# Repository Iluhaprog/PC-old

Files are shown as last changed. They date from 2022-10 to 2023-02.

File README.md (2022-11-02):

# Computer from scratch 

## Control unit

Операции
1. Сложение
2. Вычитание
3. Сдвиг влево
4. Сдвиг вправо
5. Записать значение в регистр A
6. Записать значение в регистр B
7. Условный переход при A > B
8. Условный переход при A < B
9. Условный переход при A = B
10. Завершить программу

> ### Условные обозначения
> 
> **RW**: read - "0", write - "1"
> 
> **EN**: enable - "1", disable - "0"
> 
> **HS**: hide - "1", show- "0"

> ### Устройства:
> - СК - Счетчик команд
> - РКК - Регистр кода команды
> - РА - Регистр А
> - РВ - Регистр В
> - РПА - Регистр пользовательского адреса
> - РР - Регистр результата
> - АЛУ - Арифметико-логичекое устройство
> - РФ - Регистр флагов

<h2>Формат команды</h2>
<div style="padding: 20px 10px 10px 20px; border-left: 2px solid grey; margin-bottom: 20px">

<span style="border: 3px solid orange">**код операции**</span>
<span style="border: 3px solid pink">адрес</span>

</div>

### 1. Операция сложения 

Код операции - **0001**

Адрес - номер места в ОЗУ, куда необходимо записать результат

Действия для выполнения:

1. Выключаем счетчик команд
2. Включаем чтение из ОЗУ **[R]** `0`
3. Включаем выводы ОЗУ **[EN]** `1` на чтение
4. Включаем запись в регистр пользовательских адресов (РПА) **[R]** `1`
5. Включаем выводы РПА **[EN]** для записи `1`
6. Выключаем выводы РПА **[EN]**  для записи `0`
7. Включаем запись в регистр кода команды (РКК) **[W]** `1`
8. Включаем выводы РКК **[EN]** для записи `1`
9. Выключаем выводы РКК **[EN]**  для записи `0`
10. Включаем чтение из РКК **[R]** `1`
11. Включаем выводы РКК **[EN]** для чтения `0`
12. Включаем выводы **Mode** `1`
13. Выключаем выводы ОЗУ **[EN]** `0` на чтение
14. Включаем выводы АЛУ **[EN]** для чтения
15. Включаем на запись регистр результата (РР) **[W]** `1`
16. Включаем выводы РР **[EN]** `1` для записи
17. Выключаем выводы РР **[EN]** `0` для записи
18. Выключаем выводы AЛУ **[EN]** `0` для чтения
19. Включаем чтение РР **[R]** `0`
20. Включаем выводы РР **[EN]** `1` для чтения
21. Выключаем вывод адреса из счетчика команд **[HS]** `1`
22. Включаем чтение РПА **[R]** `0`
23. Включаем выводы РПА **[EN]** `1` для чтения
24. Включаем ОЗУ на запись **[W]** `1`
25. Включаем выводы ОЗУ  **[EN]** `1` для записи
26. Выключаем выводы ОЗУ  **[EN]** `0` для записи
27. Выключаем выводы РПА **[EN]** `0` для чтения
28. Включаем вывод адреса из счетчика команд **[HS]** `0`
29. Выключаем выводы РР **[EN]** `0` для чтения
30. Включаем счетчик команд

Выводы :
1. EN СК
2. HS CK
3. EN ОЗУ
4. RW ОЗУ
5. EN РКК
6. RW РКК
7. EN PA
8. RW PA
9. EN PB
10. RW PB
11. EN PP
12. RW PP
13. EN РПА
14. RW РПА
15. АЛУ 1-бит (для выбора варианта работы АЛУ)
16. АЛУ 2-бит (для выбора варианта работы АЛУ)
17. EN АЛУ (чтение с выхода)
18. EN РФ
19. RW РФ

| Такт | Состояния на выходе | Действия |
|---|---|---|
| 1 | 0010110000001100000 | 1,2,3,4,5,6,7,8 |
| 2 | 0000101010110000100 | 9,10,11,12,13,14,15,16 |
| 3 | 0111000000101000000 | 16,17,18,19,20,21,22,23,24 |
| 4 | 1000000000000000000 | 24,25,26,27,28,28,30 |

### 2. Операция вычитания 

Код операции - **0010**

Адрес - номер места в ОЗУ, куда необходимо записать результат

Действия для выполнения:

1. Выключаем счетчик команд
2. Включаем чтение из ОЗУ **[R]** `0`
3. Включаем выводы ОЗУ **[EN]** `1` на чтение
4. Включаем запись в регистр пользовательских адресов (РПА) **[R]** `1`
5. Включаем выводы РПА **[EN]** для записи `1`
6. Выключаем выводы РПА **[EN]**  для записи `0`
7. Включаем запись в регистр кода команды (РКК) **[W]** `1`
8. Включаем выводы РКК **[EN]** для записи `1`
9. Выключаем выводы РКК **[EN]**  для записи `0`
10. Включаем чтение из РКК **[R]** `1`
11. Включаем выводы РКК **[EN]** для чтения `0`
12. Включаем выводы **Mode** `10`
13. Выключаем выводы ОЗУ **[EN]** `0` на чтение
14. Включаем выводы АЛУ **[EN]** для чтения
15. Включаем на запись регистр результата (РР) **[W]** `1`
16. Включаем выводы РР **[EN]** `1` для записи
17. Выключаем выводы РР **[EN]** `0` для записи
18. Выключаем выводы AЛУ **[EN]** `0` для чтения
19. Включаем чтение РР **[R]** `0`
20. Включаем выводы РР **[EN]** `1` для чтения
21. Выключаем вывод адреса из счетчика команд **[HS]** `1`
22. Включаем чтение РПА **[R]** `0`
23. Включаем выводы РПА **[EN]** `1` для чтения
24. Включаем ОЗУ на запись **[W]** `1`
25. Включаем выводы ОЗУ  **[EN]** `1` для записи
26. Выключаем выводы ОЗУ  **[EN]** `0` для записи
27. Выключаем выводы РПА **[EN]** `0` для чтения
28. Включаем вывод адреса из счетчика команд **[HS]** `0`
29. Выключаем выводы РР **[EN]** `0` для чтения
30. Включаем счетчик команд

Выводы :
1. EN СК
2. HS CK
3. EN ОЗУ
4. RW ОЗУ
5. EN РКК
6. RW РКК
7. EN PA
8. RW PA
9. EN PB
10. RW PB
11. EN PP
12. RW PP
13. EN РПА
14. RW РПА
15. АЛУ 1-бит (для выбора варианта работы АЛУ)
16. АЛУ 2-бит (для выбора варианта работы АЛУ)
17. EN АЛУ (чтение с выхода)
18. EN РФ
19. RW РФ

| Такт | Состояния на выходе | Действия |
|---|---|---|
| 1 | 0010110000001100000 | 1,2,3,4,5,6,7,8 |
| 2 | 0000101010110010100 | 9,10,11,12,13,14,15,16 |
| 3 | 0111000000101000000 | 16,17,18,19,20,21,22,23,24 |
| 4 | 1000000000000000000 | 24,25,26,27,28,28,30 |

### 3. Операция сдвига влево 

Код операции - **0011**

Адрес - номер места в ОЗУ, куда необходимо записать результат

Действия для выполнения:

1. Выключаем счетчик команд
2. Включаем чтение из ОЗУ **[R]** `0`
3. Включаем выводы ОЗУ **[EN]** `1` на чтение
4. Включаем запись в регистр пользовательских адресов (РПА) **[R]** `1`
5. Включаем выводы РПА **[EN]** для записи `1`
6. Выключаем выводы РПА **[EN]**  для записи `0`
7. Включаем запись в регистр кода команды (РКК) **[W]** `1`
8. Включаем выводы РКК **[EN]** для записи `1`
9. Выключаем выводы РКК **[EN]**  для записи `0`
10. Включаем чтение из РКК **[R]** `1`
11. Включаем выводы РКК **[EN]** для чтения `0`
12. Включаем выводы **Mode** `11`
13. Выключаем выводы ОЗУ **[EN]** `0` на чтение
14. Включаем выводы АЛУ **[EN]** для чтения
15. Включаем на запись регистр результата (РР) **[W]** `1`
16. Включаем выводы РР **[EN]** `1` для записи
17. Выключаем выводы РР **[EN]** `0` для записи
18. Выключаем выводы AЛУ **[EN]** `0` для чтения
19. Включаем чтение РР **[R]** `0`
20. Включаем выводы РР **[EN]** `1` для чтения
21. Выключаем вывод адреса из счетчика команд **[HS]** `1`
22. Включаем чтение РПА **[R]** `0`
23. Включаем выводы РПА **[EN]** `1` для чтения
24. Включаем ОЗУ на запись **[W]** `1`
25. Включаем выводы ОЗУ  **[EN]** `1` для записи
26. Выключаем выводы ОЗУ  **[EN]** `0` для записи
27. Выключаем выводы РПА **[EN]** `0` для чтения
28. Включаем вывод адреса из счетчика команд **[HS]** `0`
29. Выключаем выводы РР **[EN]** `0` для чтения
30. Включаем счетчик команд

Выводы :
1. EN СК
2. HS CK
3. EN ОЗУ
4. RW ОЗУ
5. EN РКК
6. RW РКК
7. EN PA
8. RW PA
9. EN PB
10. RW PB
11. EN PP
12. RW PP
13. EN РПА
14. RW РПА
15. АЛУ 1-бит (для выбора варианта работы АЛУ)
16. АЛУ 2-бит (для выбора варианта работы АЛУ)
17. EN АЛУ (чтение с выхода)
18. EN РФ
19. RW РФ

| Такт | Состояния на выходе | Действия |
|---|---|---|
| 1 | 0010110000001100000 | 1,2,3,4,5,6,7,8 |
| 2 | 0000101010110011100 | 9,10,11,12,13,14,15,16 |
| 3 | 0111000000101000000 | 16,17,18,19,20,21,22,23,24 |
| 4 | 1000000000000000000 | 24,25,26,27,28,28,30 |

### 3. Операция сдвига вправо 

Код операции - **0100**

Адрес - номер места в ОЗУ, куда необходимо записать результат

Действия для выполнения:

1. Выключаем счетчик команд
2. Включаем чтение из ОЗУ **[R]** `0`
3. Включаем выводы ОЗУ **[EN]** `1` на чтение
4. Включаем запись в регистр пользовательских адресов (РПА) **[R]** `1`
5. Включаем выводы РПА **[EN]** для записи `1`
6. Выключаем выводы РПА **[EN]**  для записи `0`
7. Включаем запись в регистр кода команды (РКК) **[W]** `1`
8. Включаем выводы РКК **[EN]** для записи `1`
9. Выключаем выводы РКК **[EN]**  для записи `0`
10. Включаем чтение из РКК **[R]** `1`
11. Включаем выводы РКК **[EN]** для чтения `0`
12. Включаем выводы **Mode** `11`
13. Выключаем выводы ОЗУ **[EN]** `0` на чтение
14. Включаем выводы АЛУ **[EN]** для чтения
15. Включаем на запись регистр результата (РР) **[W]** `1`
16. Включаем выводы РР **[EN]** `1` для записи
17. Выключаем выводы РР **[EN]** `0` для записи
18. Выключаем выводы AЛУ **[EN]** `0` для чтения
19. Включаем чтение РР **[R]** `0`
20. Включаем выводы РР **[EN]** `1` для чтения
21. Выключаем вывод адреса из счетчика команд **[HS]** `1`
22. Включаем чтение РПА **[R]** `0`
23. Включаем выводы РПА **[EN]** `1` для чтения
24. Включаем ОЗУ на запись **[W]** `1`
25. Включаем выводы ОЗУ  **[EN]** `1` для записи
26. Выключаем выводы ОЗУ  **[EN]** `0` для записи
27. Выключаем выводы РПА **[EN]** `0` для чтения
28. Включаем вывод адреса из счетчика команд **[HS]** `0`
29. Выключаем выводы РР **[EN]** `0` для чтения
30. Включаем счетчик команд

Выводы :
1. EN СК
2. HS CK
3. EN ОЗУ
4. RW ОЗУ
5. EN РКК
6. RW РКК
7. EN PA
8. RW PA
9. EN PB
10. RW PB
11. EN PP
12. RW PP
13. EN РПА
14. RW РПА
15. АЛУ 1-бит (для выбора варианта работы АЛУ)
16. АЛУ 2-бит (для выбора варианта работы АЛУ)
17. EN АЛУ (чтение с выхода)
18. EN РФ
19. RW РФ

| Такт | Состояния на выходе | Действия |
|---|---|---|
| 1 | 0010110000001100000 | 1,2,3,4,5,6,7,8 |
| 2 | 0000101010110001100 | 9,10,11,12,13,14,15,16 |
| 3 | 0111000000101000000 | 16,17,18,19,20,21,22,23,24 |
| 4 | 1000000000000000000 | 24,25,26,27,28,28,30 |

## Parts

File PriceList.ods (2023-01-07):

Устройства выбора режима работы АЛУ, сумматор вычитатель, выводное устройство |  |  |  |  | Дополнительные элементы
Логический элемент | Модель микросхемы | Стоимость | Количество | Сумма | Элемент | Количество | Стоимость | Сумма
2И | SN74HC08N | 1.9 | 9 | 17.1 | DIP-14 панели | 30 | 0.2 | 6
НЕ | SN74HC05N | 1.9 | 6 | 11.4 | Вилка (1 на 40) | 1 | 2.05 | 2.05
XOR | SN74HC86N | 1.45 | 7 | 10.15 | Резисторы 1кОМ | 40 | 0.08 | 3.2
2ИЛИ | SN74HC32N | 1.75 | 4 | 7 | Конденсатры 1мкФ | 40 | 0.2 | 8
3ИЛИ-НЕ | SN74HC27N | 1.15 | 4 | 4.6
 |  |  |  |  |  | я
Общая стоимость |  |  | 30 | 50.25 |  |  |  | 19.25
Сумма
69.5

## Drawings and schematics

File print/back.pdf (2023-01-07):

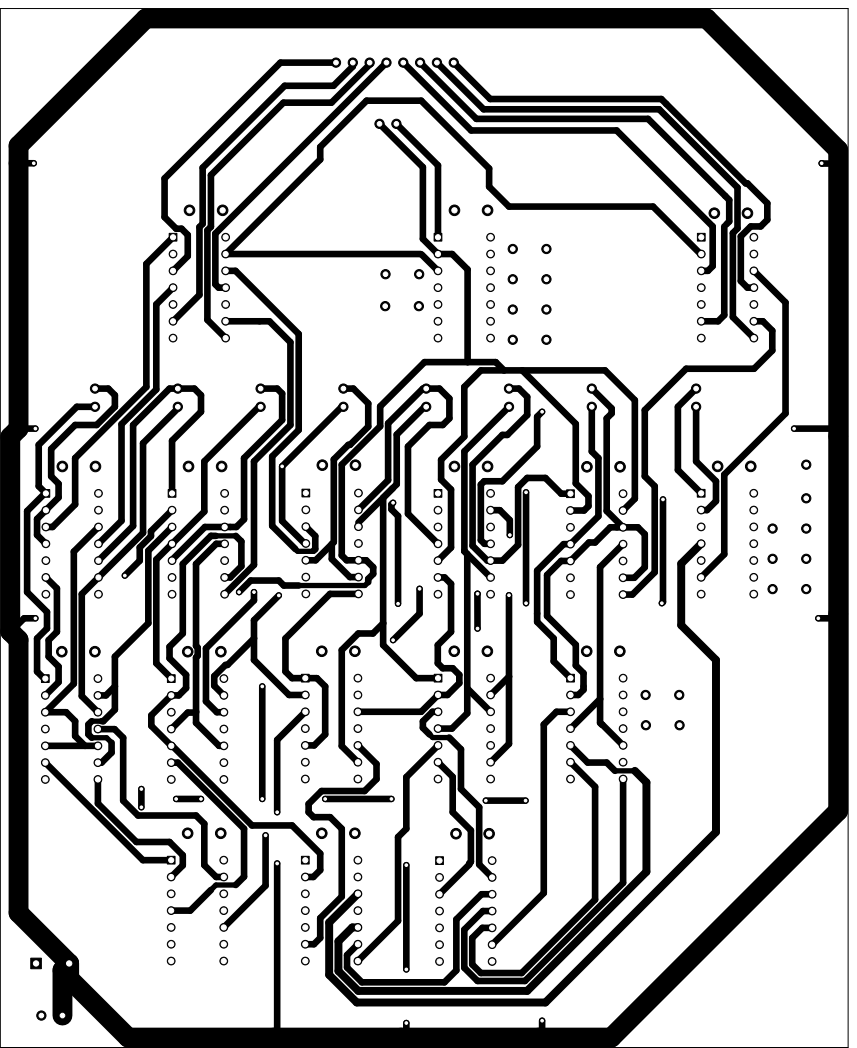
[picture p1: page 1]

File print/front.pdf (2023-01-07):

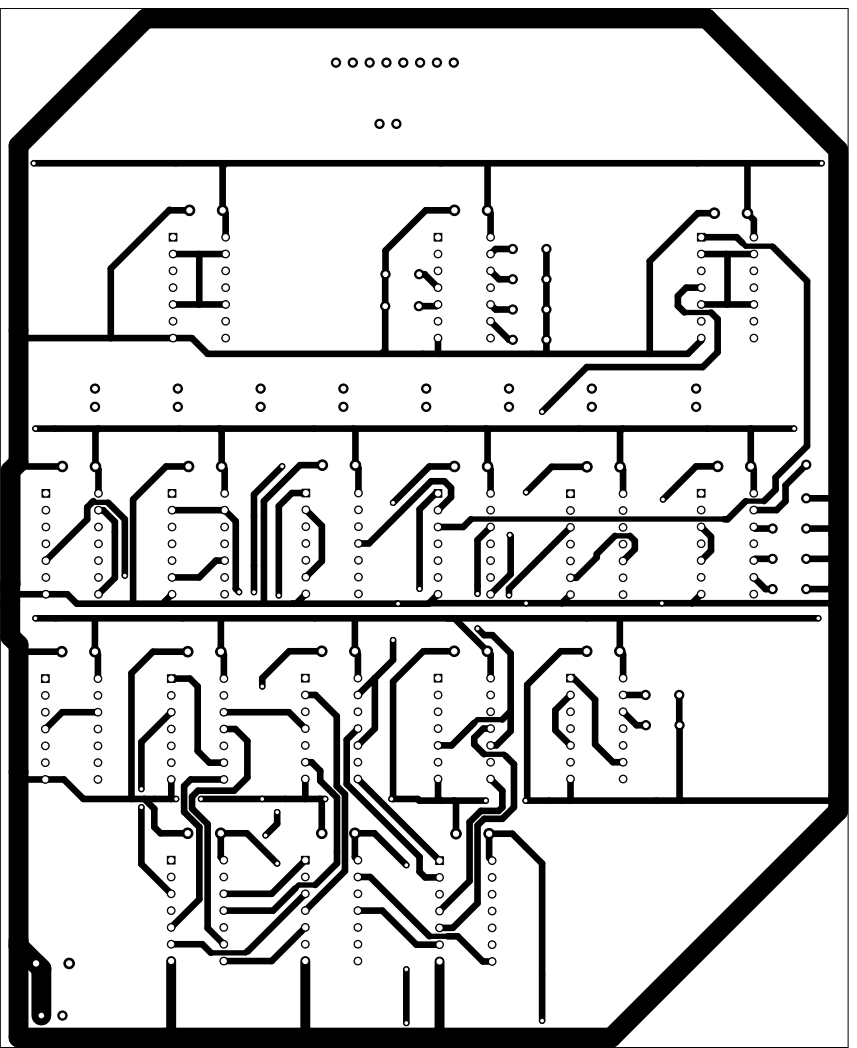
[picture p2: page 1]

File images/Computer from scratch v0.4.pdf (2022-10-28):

? ??

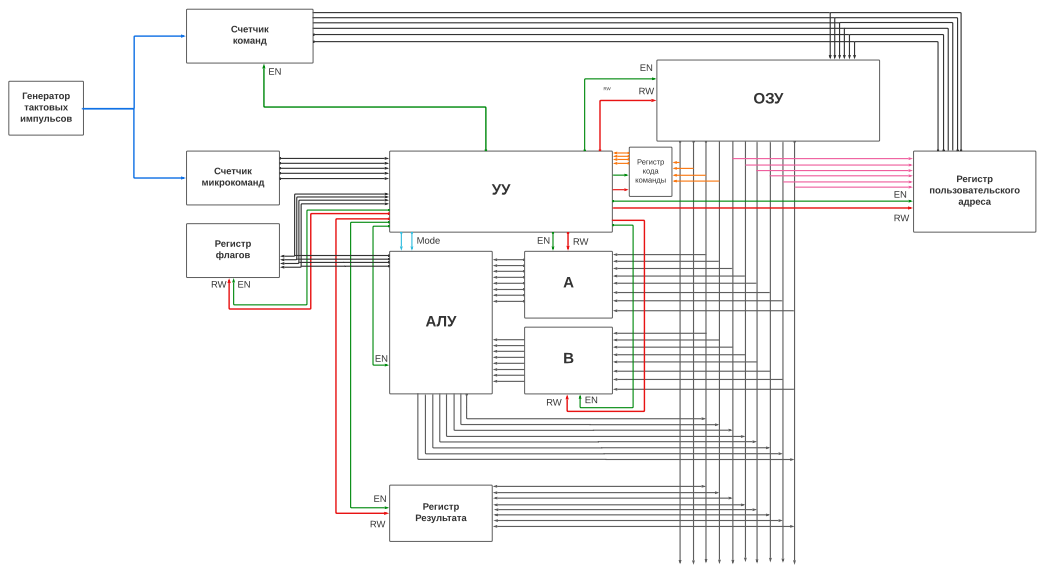
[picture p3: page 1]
Mode

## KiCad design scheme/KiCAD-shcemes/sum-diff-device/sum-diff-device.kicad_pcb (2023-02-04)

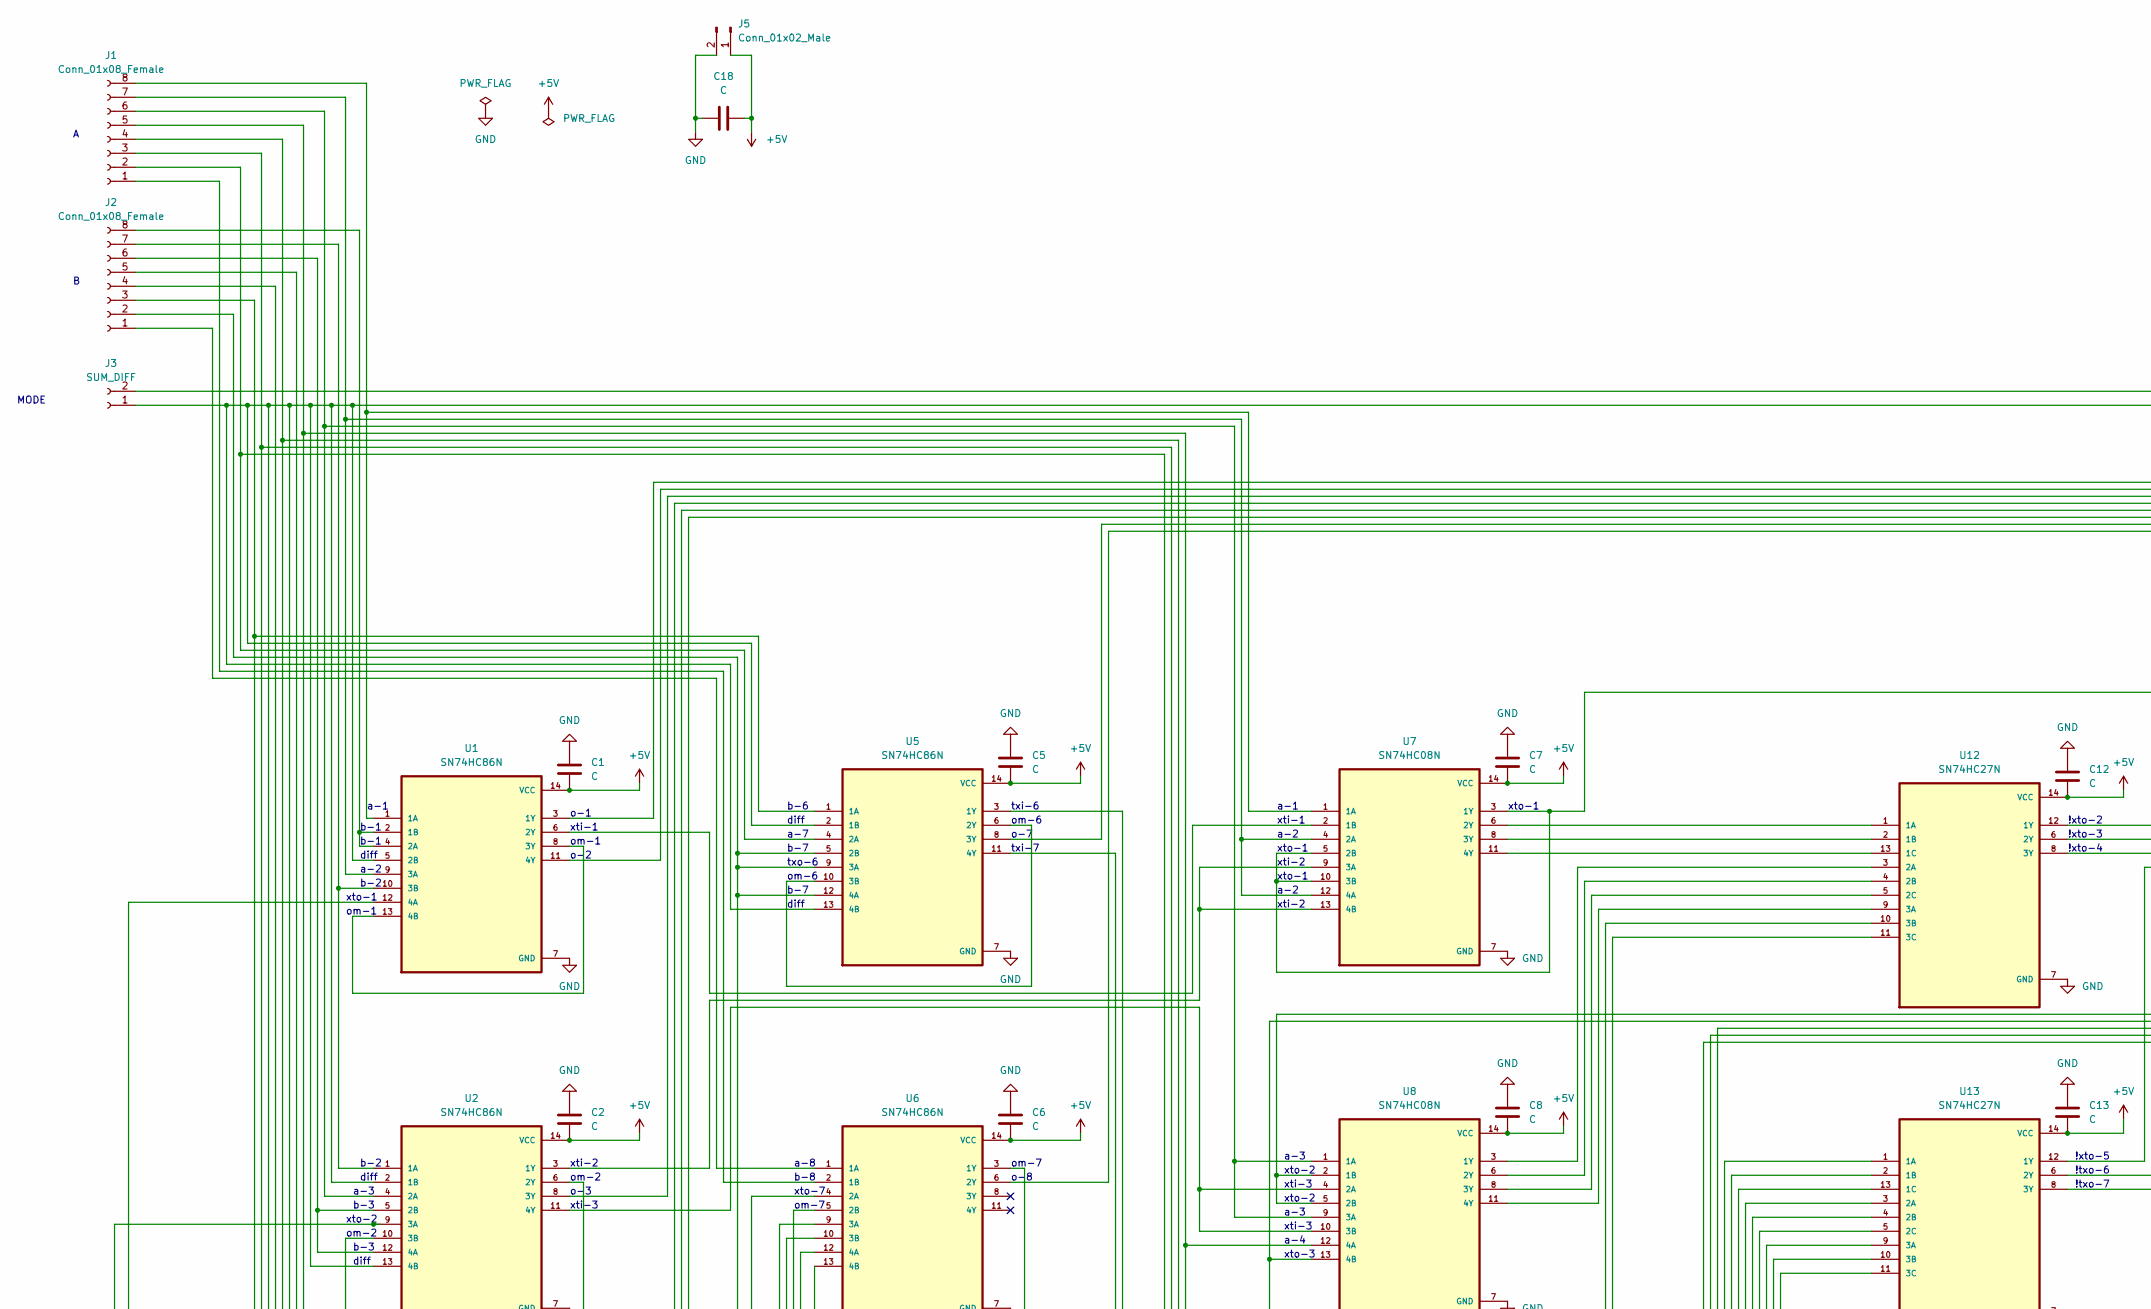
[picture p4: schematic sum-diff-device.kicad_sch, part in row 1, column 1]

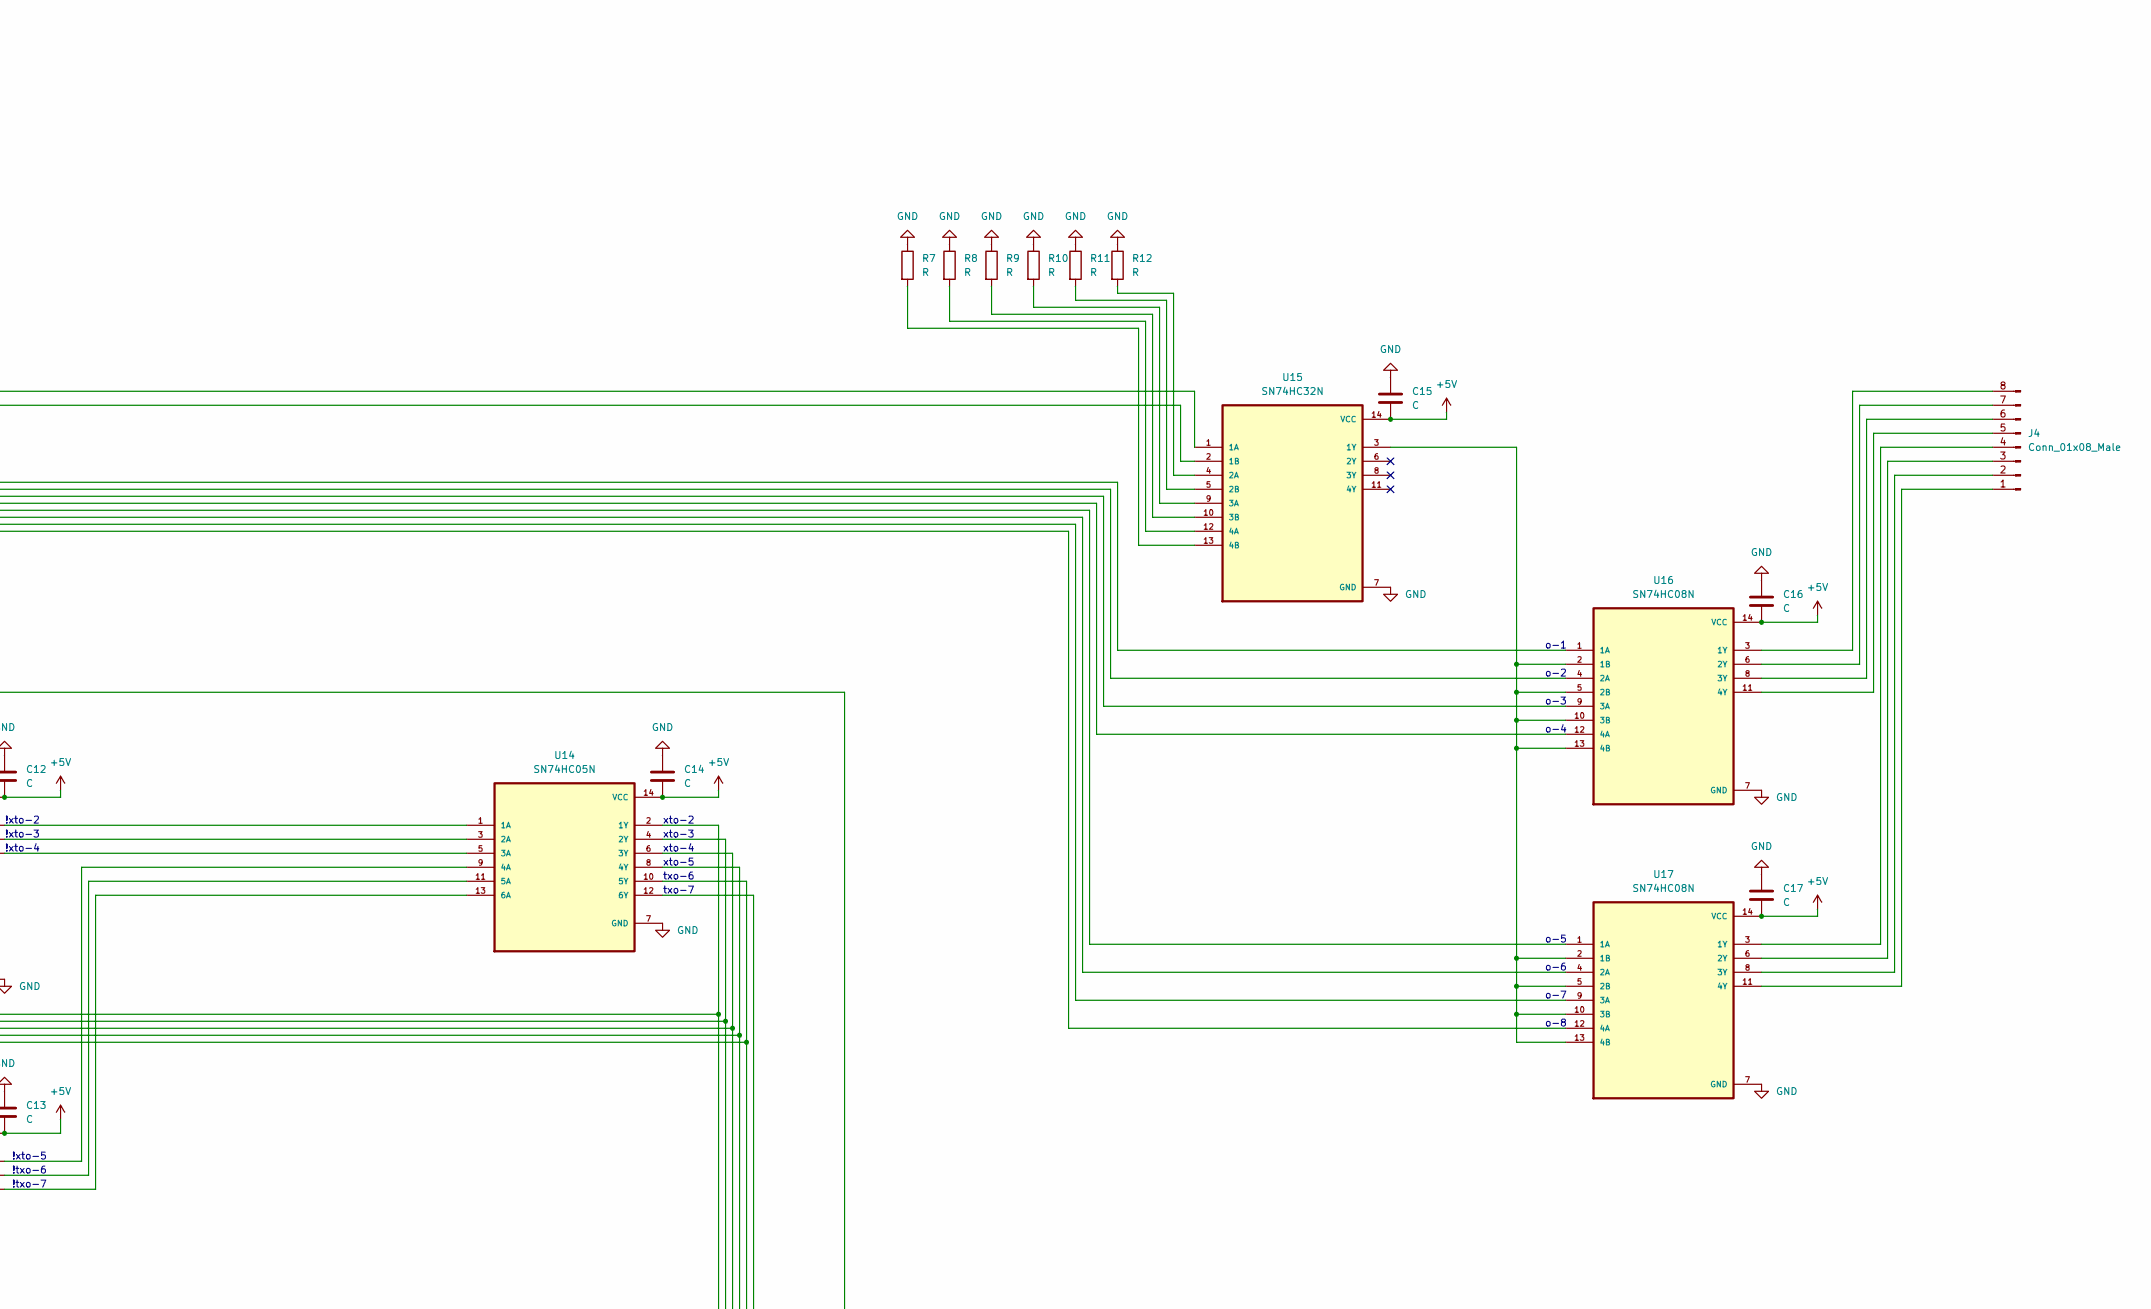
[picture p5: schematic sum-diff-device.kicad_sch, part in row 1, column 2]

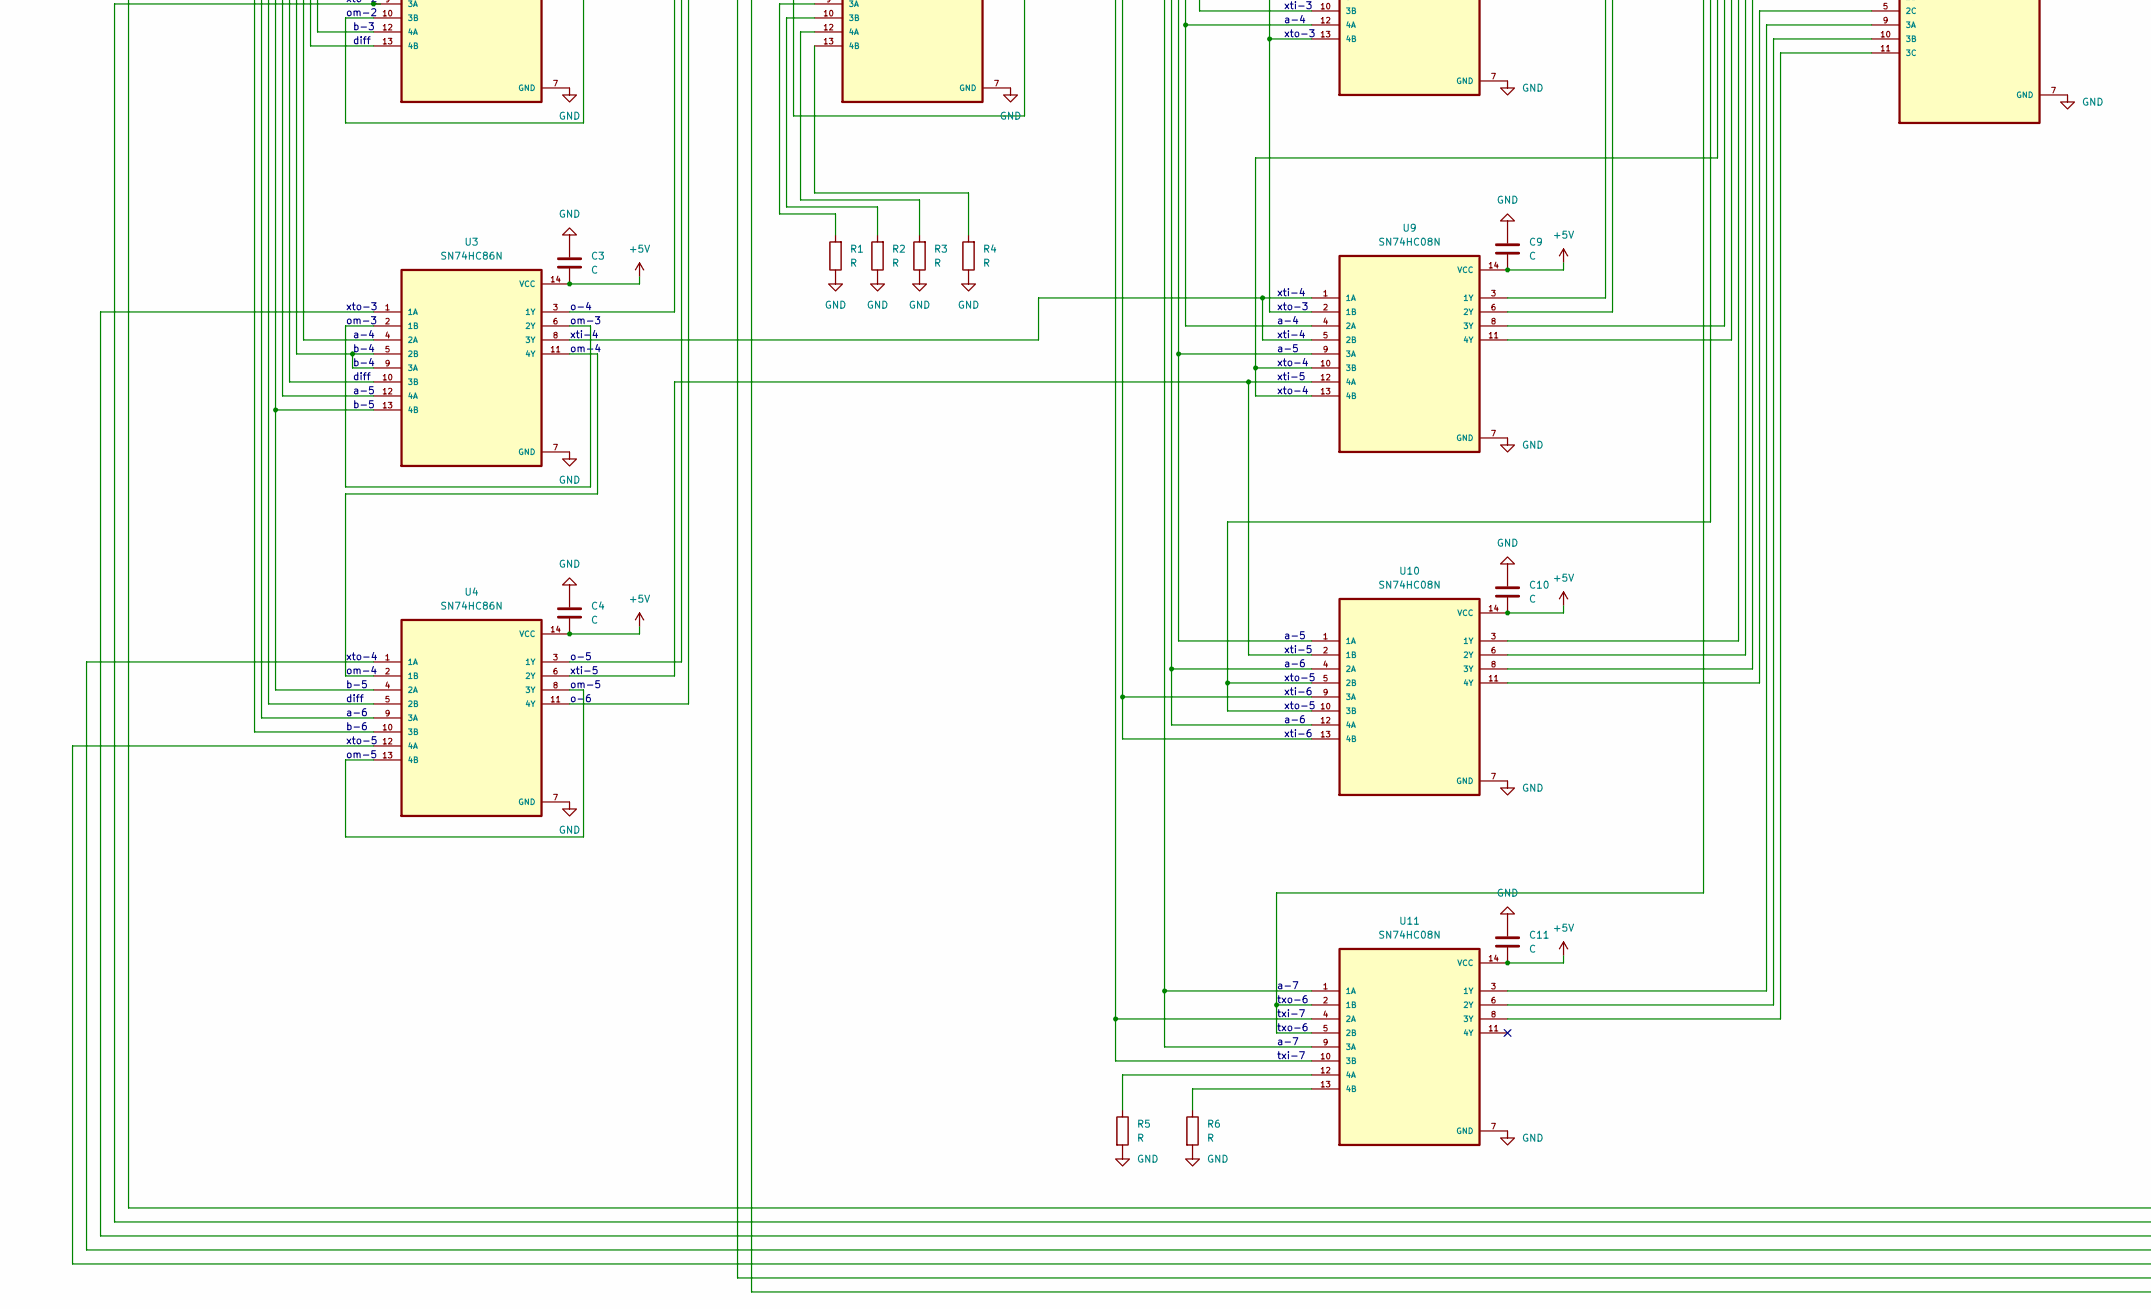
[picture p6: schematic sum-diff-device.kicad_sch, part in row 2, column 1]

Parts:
C1, C2, C3, C4, C5, C6, C7, C8, C9, C10, C11, C12, C13, C14, C15, C16, C17: C; C_Rect_L7.0mm_W2.0mm_P5.00mm
C18: C; CP_Radial_D8.0mm_P5.00mm
J1, J2: Conn_01x08_Female; PinHeader_1x08_P2.54mm_Vertical
J3: SUM_DIFF; PinSocket_1x02_P2.54mm_Vertical
J4: Conn_01x08_Male; PinHeader_1x08_P2.54mm_Vertical
J5: Conn_01x02_Male; PinSocket_1x02_P2.54mm_Vertical
R1, R2, R3, R4, R5, R6, R7, R8, R9, R10, R11, R12: R; R_Axial_DIN0204_L3.6mm_D1.6mm_P5.08mm_Vertical
U1, U2, U3, U4, U5, U6: SN74HC86N; DIP794W45P254L1969H508Q14
U7, U8, U9, U10, U11, U16, U17: SN74HC08N; DIP794W45P254L1969H508Q14
U12, U13: SN74HC27N; DIP794W45P254L1969H508Q14
U14: SN74HC05N; DIP794W45P254L1969H508Q14
U15: SN74HC32N; DIP794W45P254L1969H508Q14

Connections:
+5V: C1.2, C2.2, C3.2, C4.2, C5.2, C6.2, C7.2, C8.2, C9.2, C10.2, C11.2, C12.2, C13.2, C14.2, C15.2, C16.2, C17.2, C18.2, J5.1, U1.14 (VCC), U2.14 (VCC), U3.14 (VCC), U4.14 (VCC), U5.14 (VCC), U6.14 (VCC), U7.14 (VCC), U8.14 (VCC), U9.14 (VCC), U10.14 (VCC), U11.14 (VCC), U12.14 (VCC), U13.14 (VCC), U14.14 (VCC), U15.14 (VCC), U16.14 (VCC), U17.14 (VCC)
GND: C1.1, C2.1, C3.1, C4.1, C5.1, C6.1, C7.1, C8.1, C9.1, C10.1, C11.1, C12.1, C13.1, C14.1, C15.1, C16.1, C17.1, C18.1, J5.2, R1.1, R2.1, R3.1, R4.1, R5.2, R6.2, R7.1, R8.1, R9.1, R10.1, R11.1, R12.1, U1.7 (GND), U2.7 (GND), U3.7 (GND), U4.7 (GND), U5.7 (GND), U6.7 (GND), U7.7 (GND), U8.7 (GND), U9.7 (GND), U10.7 (GND), U11.7 (GND), U12.7 (GND), U13.7 (GND), U14.7 (GND), U15.7 (GND), U16.7 (GND), U17.7 (GND)
unnamed: J1.1, U6.2 (1B)
unnamed: J1.2, U5.4 (2A), U11.1 (1A), U11.9 (3A)
unnamed: J1.4, U3.12 (4A), U9.9 (3A), U10.1 (1A)
unnamed: J1.5, U3.4 (2A), U8.12 (4A), U9.4 (2A)
unnamed: J1.6, U2.4 (2A), U8.1 (1A), U8.9 (3A)
unnamed: J1.7, U1.9 (3A), U7.4 (2A), U7.12 (4A)
unnamed: J1.8, U1.1 (1A), U7.1 (1A)
unnamed: J2.1, U6.1 (1A)
unnamed: J2.2, U5.5 (2B), U5.9 (3A), U5.12 (4A), U11.2 (1B), U11.5 (2B), U14.10 (5Y)
unnamed: J2.3, U4.10 (3B), U5.1 (1A)
unnamed: J2.4, U3.13 (4B), U4.4 (2A)
unnamed: J2.5, U3.5 (2B), U3.9 (3A)
unnamed: J2.7, U1.10 (3B), U2.1 (1A)
unnamed: J2.8, U1.2 (1B), U1.4 (2A)
unnamed: J3.1, U1.5 (2B), U2.2 (1B), U2.13 (4B), U3.10 (3B), U4.5 (2B), U5.2 (1B), U5.13 (4B), U15.2 (1B)
unnamed: J3.2, U15.1 (1A)
unnamed: J4.1, U17.11 (4Y)
unnamed: J4.2, U17.8 (3Y)
unnamed: J4.4, U17.3 (1Y)
unnamed: J4.5, U16.11 (4Y)
unnamed: J4.6, U16.8 (3Y)
unnamed: J4.8, U16.3 (1Y)
unnamed: R1.2, U6.9 (3A)
unnamed: R2.2, U6.10 (3B)
unnamed: R3.2, U6.12 (4A)
unnamed: R4.2, U6.13 (4B)
unnamed: R5.1, U11.12 (4A)
unnamed: R6.1, U11.13 (4B)
unnamed: R7.2, U15.13 (4B)
unnamed: R8.2, U15.12 (4A)
unnamed: R9.2, U15.10 (3B)
unnamed: R10.2, U15.9 (3A)
unnamed: R11.2, U15.5 (2B)
unnamed: R12.2, U15.4 (2A)
unnamed: U1.3 (1Y), U16.1 (1A)
unnamed: U1.6 (2Y), U7.2 (1B)
unnamed: U1.11 (4Y), U16.4 (2A)
unnamed: U1.12 (4A), U7.3 (1Y), U7.5 (2B), U7.10 (3B)
unnamed: U1.8 (3Y), U1.13 (4B)
unnamed: U2.3 (1Y), U7.9 (3A), U7.13 (4B)
unnamed: U2.6 (2Y), U2.10 (3B)
unnamed: U2.11 (4Y), U8.4 (2A), U8.10 (3B)
unnamed: J2.6, U2.5 (2B), U2.12 (4A)
unnamed: U3.2 (1B), U3.6 (2Y)
unnamed: U3.8 (3Y), U9.1 (1A), U9.5 (2B)
unnamed: U3.11 (4Y), U4.2 (1B)
unnamed: U4.8 (3Y), U4.13 (4B)
unnamed: U5.6 (2Y), U5.10 (3B)
unnamed: U6.3 (1Y), U6.5 (2B)
unnamed: U4.6 (2Y), U9.12 (4A), U10.2 (1B)
unnamed: U10.3 (1Y), U13.13 (1C)
unnamed: U10.6 (2Y), U13.3 (2A)
unnamed: U10.8 (3Y), U13.4 (2B)
unnamed: U4.12 (4A), U10.5 (2B), U10.10 (3B), U14.8 (4Y)
unnamed: U10.11 (4Y), U13.5 (2C)
unnamed: J1.3, U4.9 (3A), U10.4 (2A), U10.12 (4A)
unnamed: U5.3 (1Y), U10.9 (3A), U10.13 (4B)
unnamed: U11.3 (1Y), U13.9 (3A)
unnamed: U11.6 (2Y), U13.10 (3B)
unnamed: U11.8 (3Y), U13.11 (3C)
unnamed: U5.11 (4Y), U11.4 (2A), U11.10 (3B)
unnamed: U7.6 (2Y), U12.1 (1A)
unnamed: U7.8 (3Y), U12.2 (1B)
unnamed: U8.3 (1Y), U12.3 (2A)
unnamed: U8.6 (2Y), U12.4 (2B)
unnamed: U8.8 (3Y), U12.5 (2C)
unnamed: U12.6 (2Y), U14.3 (2A)
unnamed: U12.8 (3Y), U14.5 (3A)
unnamed: U8.11 (4Y), U12.9 (3A)
unnamed: U9.3 (1Y), U12.10 (3B)
unnamed: U9.6 (2Y), U12.11 (3C)
unnamed: U12.12 (1Y), U14.1 (1A)
unnamed: U7.11 (4Y), U12.13 (1C)
unnamed: U9.8 (3Y), U13.1 (1A)
unnamed: U9.11 (4Y), U13.2 (1B)
unnamed: U13.6 (2Y), U14.11 (5A)
unnamed: U13.8 (3Y), U14.13 (6A)
unnamed: U13.12 (1Y), U14.9 (4A)
unnamed: U2.9 (3A), U8.2 (1B), U8.5 (2B), U14.2 (1Y)
unnamed: U3.1 (1A), U8.13 (4B), U9.2 (1B), U14.4 (2Y)
unnamed: U4.1 (1A), U9.10 (3B), U9.13 (4B), U14.6 (3Y)
unnamed: U6.4 (2A), U14.12 (6Y)
unnamed: U15.3 (1Y), U16.2 (1B), U16.5 (2B), U16.10 (3B), U16.13 (4B), U17.2 (1B), U17.5 (2B), U17.10 (3B), U17.13 (4B)
unnamed: J4.7, U16.6 (2Y)
unnamed: U2.8 (3Y), U16.9 (3A)
unnamed: U3.3 (1Y), U16.12 (4A)
unnamed: U4.3 (1Y), U17.1 (1A)
unnamed: U4.11 (4Y), U17.4 (2A)
unnamed: J4.3, U17.6 (2Y)
unnamed: U5.8 (3Y), U17.9 (3A)
unnamed: U6.6 (2Y), U17.12 (4A)

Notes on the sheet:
a-5
xto-3
MODE
b-4
txi-7
a-3
b-2
b-3
om-2
om-7
a-6
o-1
xto-1
b-6
xti-5
om-6
diff
xti-2
!xto-5
xti-4
o-5
b-5
a-4
a-2
om-5
o-2
xto-5
o-7
xto-2
a-7
a-1
o-8
xti-3
om-3
om-4
o-4
a-8
xti-6
txo-6
b-1

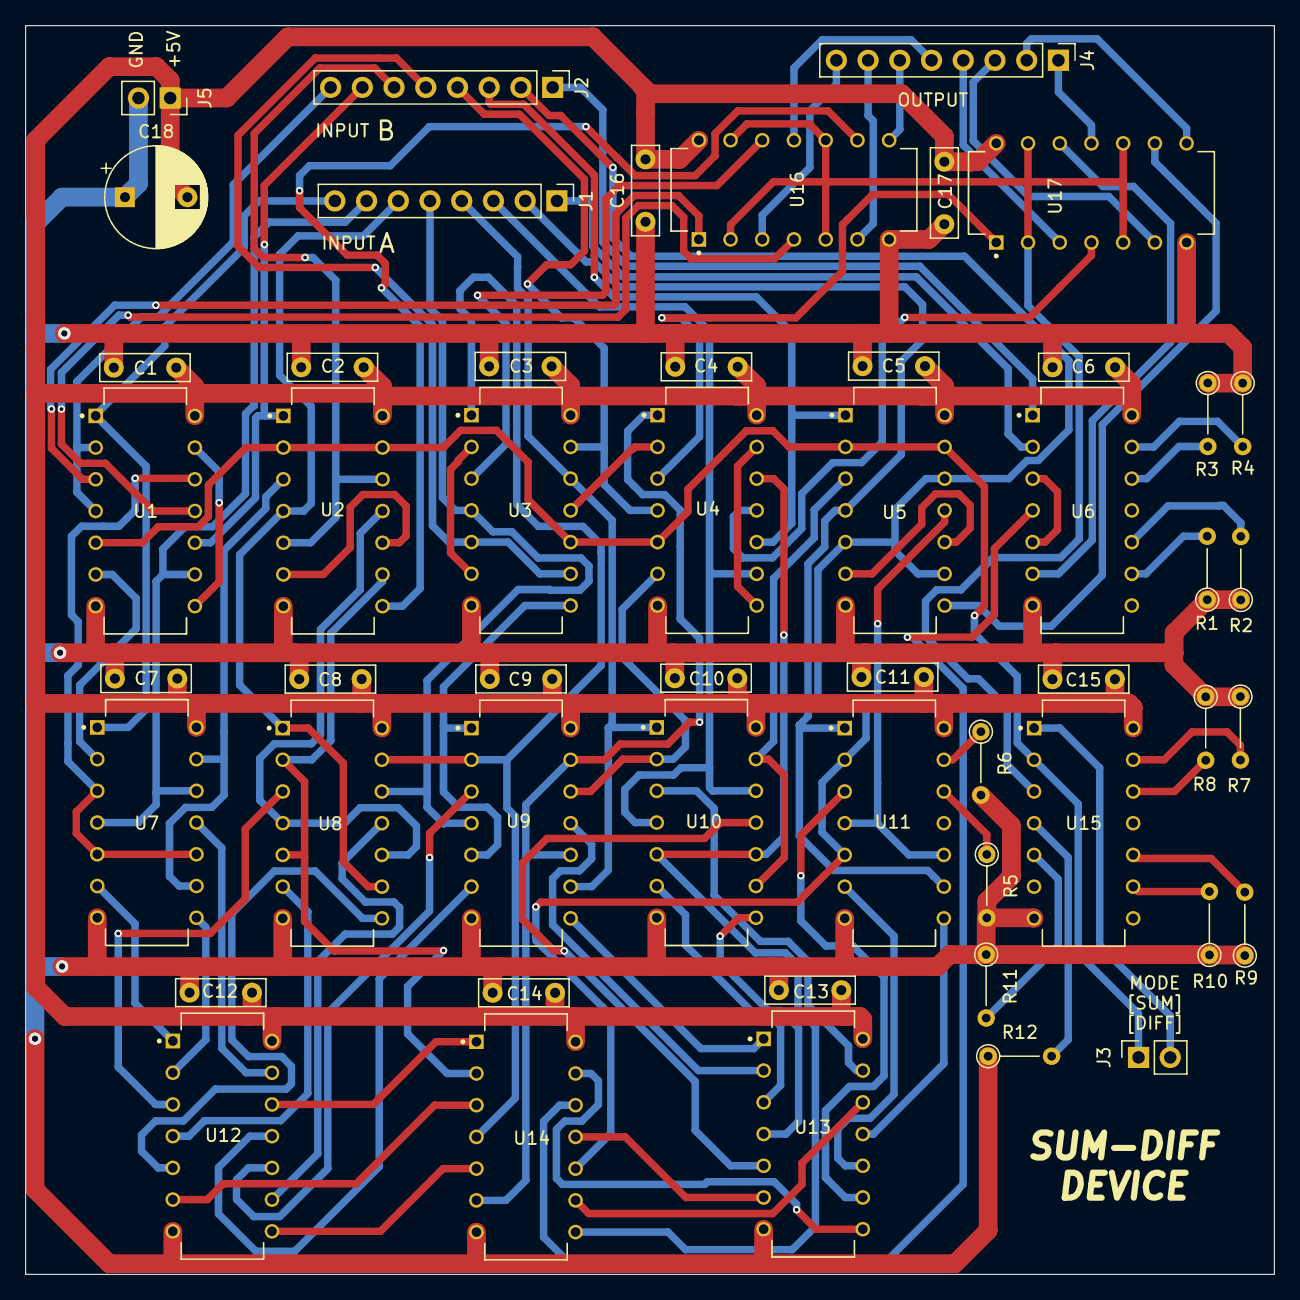
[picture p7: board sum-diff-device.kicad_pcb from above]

Board: 2 copper layers, 100.0 x 100.0 mm, 52 parts (0 on the bottom side), 93 nets.

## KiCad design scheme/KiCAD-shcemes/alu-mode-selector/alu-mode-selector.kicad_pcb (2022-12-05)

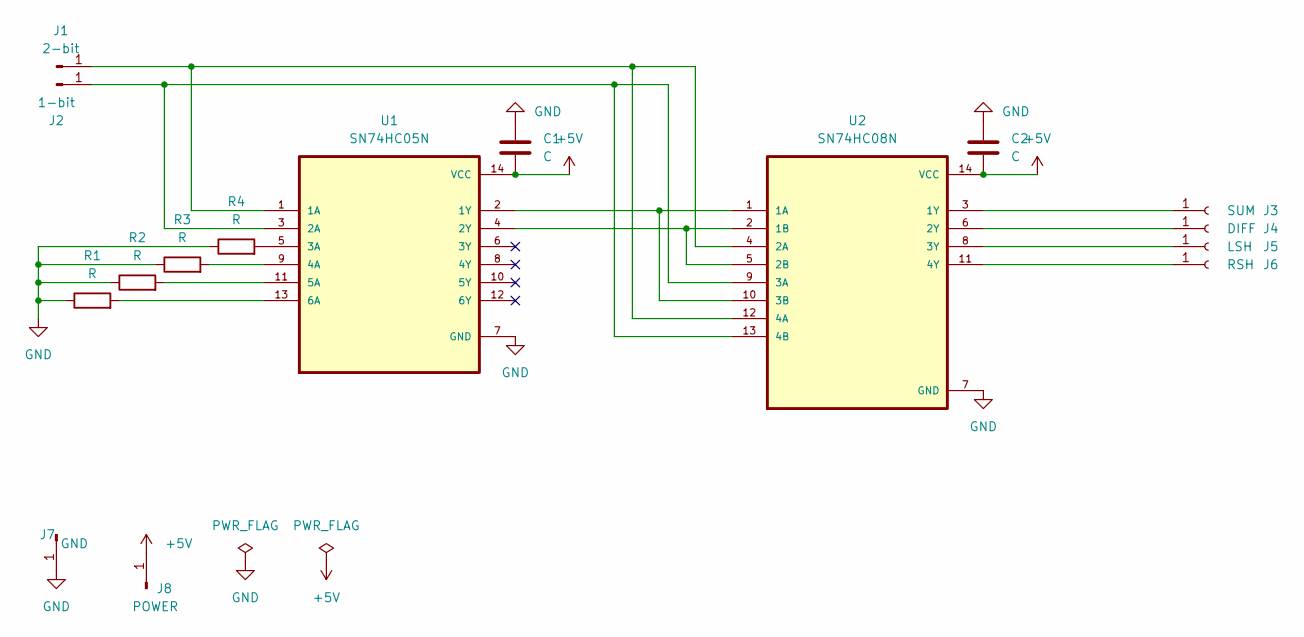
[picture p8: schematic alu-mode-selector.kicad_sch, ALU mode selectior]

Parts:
C1, C2: C; C_Rect_L7.0mm_W2.0mm_P5.00mm
J1: 2-bit; Pin_D1.3mm_L11.3mm_W2.8mm_Flat
J2: 1-bit; Pin_D1.3mm_L11.3mm_W2.8mm_Flat
J3: SUM; Pin_D1.3mm_L11.3mm_W2.8mm_Flat
J4: DIFF; Pin_D1.3mm_L11.3mm_W2.8mm_Flat
J5: LSH; Pin_D1.3mm_L11.3mm_W2.8mm_Flat
J6: RSH; Pin_D1.3mm_L11.3mm_W2.8mm_Flat
J7: GND; Pin_D1.3mm_L11.3mm_W2.8mm_Flat
J8: POWER; Pin_D1.3mm_L11.3mm_W2.8mm_Flat
R1, R2, R3, R4: R; R_Axial_DIN0411_L9.9mm_D3.6mm_P5.08mm_Vertical
U1: SN74HC05N; DIP794W45P254L1969H508Q14
U2: SN74HC08N; DIP794W45P254L1969H508Q14

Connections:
+5V: C1.1, C2.1, J8.1, U1.14 (VCC), U2.14 (VCC)
GND: C1.2, C2.2, J7.1, R1.1, R2.1, R3.1, R4.1, U1.7 (GND), U2.7 (GND)
unnamed: J1.1, U1.1 (1A), U2.4 (2A), U2.12 (4A)
unnamed: J2.1, U1.3 (2A), U2.9 (3A), U2.13 (4B)
unnamed: J3.1, U2.3 (1Y)
unnamed: J4.1, U2.6 (2Y)
unnamed: J5.1, U2.8 (3Y)
unnamed: J6.1, U2.11 (4Y)
unnamed: R1.2, U1.13 (6A)
unnamed: R2.2, U1.11 (5A)
unnamed: R3.2, U1.9 (4A)
unnamed: R4.2, U1.5 (3A)
unnamed: U1.2 (1Y), U2.1 (1A), U2.10 (3B)
unnamed: U1.4 (2Y), U2.2 (1B), U2.5 (2B)

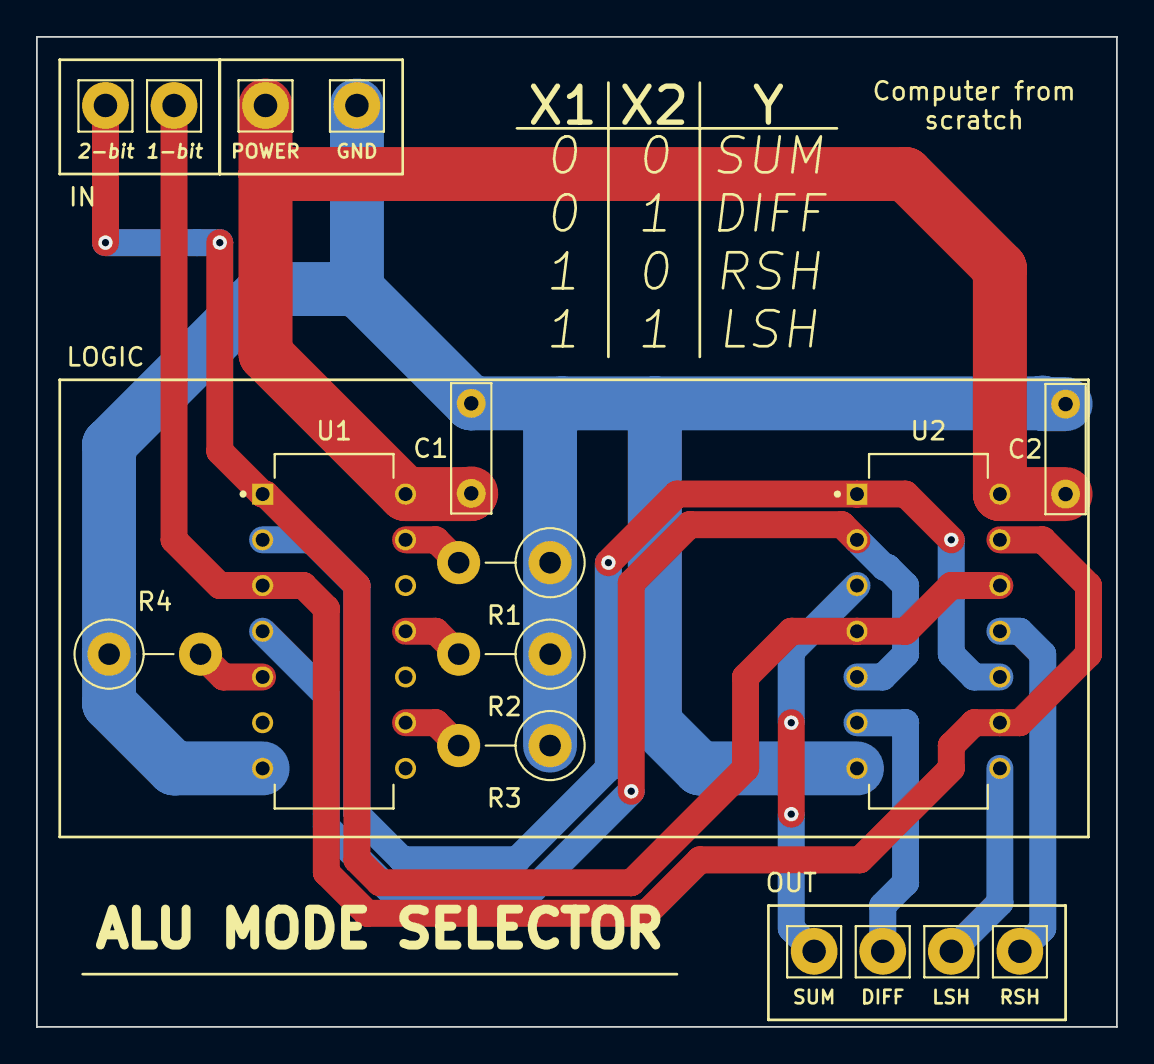
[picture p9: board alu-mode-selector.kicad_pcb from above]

Board: 2 copper layers, 60.0 x 55.0 mm, 16 parts (0 on the bottom side), 14 nets.

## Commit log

2022-09-23 feat: Created circuit for ALU.
2022-12-05 feat: Added pcb for ALU.
    [ALU_MODE_SELECTOR_v1.kicad_pcb, KiCAD-shcemes.kicad_pcb, KiCAD-shcemes.kicad_sch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]
2022-12-06 feat: Complete pcb for SUM/DIFF device.
    [sum-diff-device.kicad_pcb]
2023-01-07 feat: last version of pcb
    [PriceList.ods, sum-diff-device.kicad_pcb, sum-diff-device.kicad_sch]
2023-01-25 feat: Changed pcb for sum-diff device
    [sum-diff-device.kicad_pcb]
2023-02-02 last changes
    [sum-diff-device.kicad_sch]
2023-02-04 feat: Created build for jlcpcb.
    [sum-diff-device-B_Cu.gbl, sum-diff-device-B_Mask.gbs, sum-diff-device-B_Paste.gbp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]
